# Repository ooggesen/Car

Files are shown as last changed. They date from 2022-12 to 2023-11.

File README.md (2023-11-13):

# Remote Car

This project contains the PCB, code and CAD files for a small remotely controlled car. It is based uppon an Arduino Micro.

The PCB files are generated with KiCAD and can be found in the folder Platine.

The code for running the car can be found in the folder Code/Car_Backend and the controller from which to access the car is stored in Car/Car_Frontend.

The folder Body contains stl files, from which the body of the car could be build

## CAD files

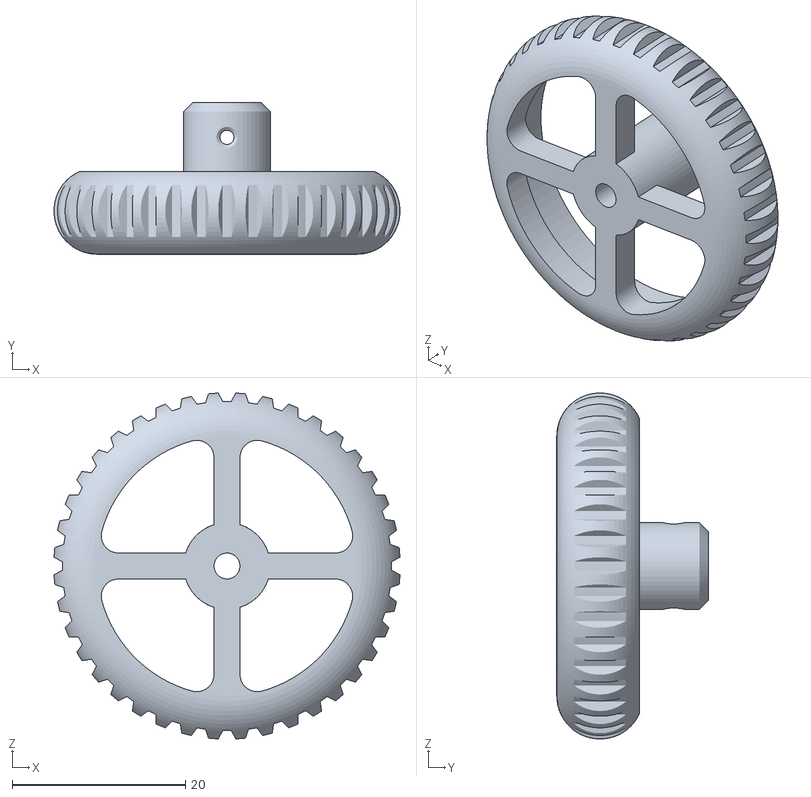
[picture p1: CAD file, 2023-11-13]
Body/Lenkrad v6.stl
39.9 x 17.5 x 39.9

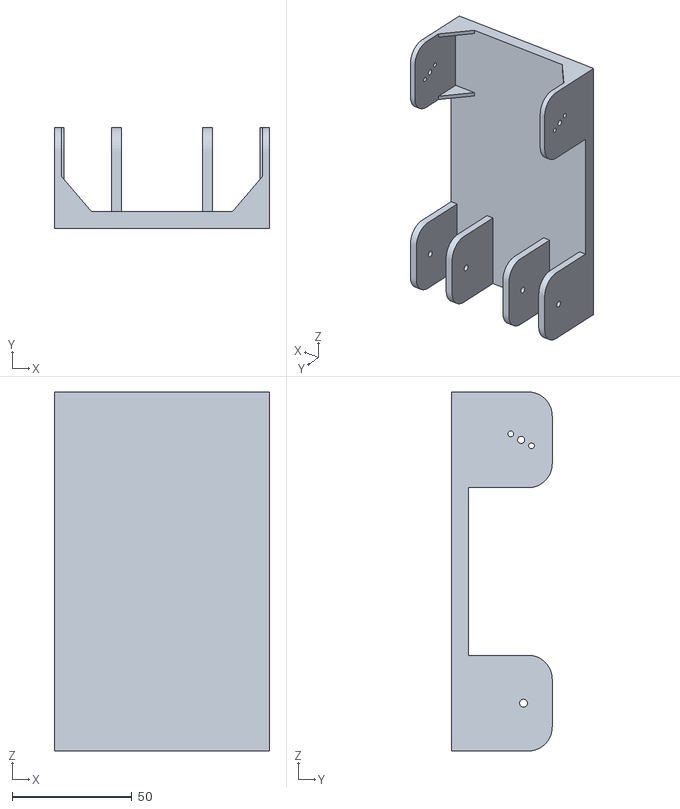
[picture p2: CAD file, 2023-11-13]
Body/Unterboden v4.stl
90.0 x 42.0 x 150.0

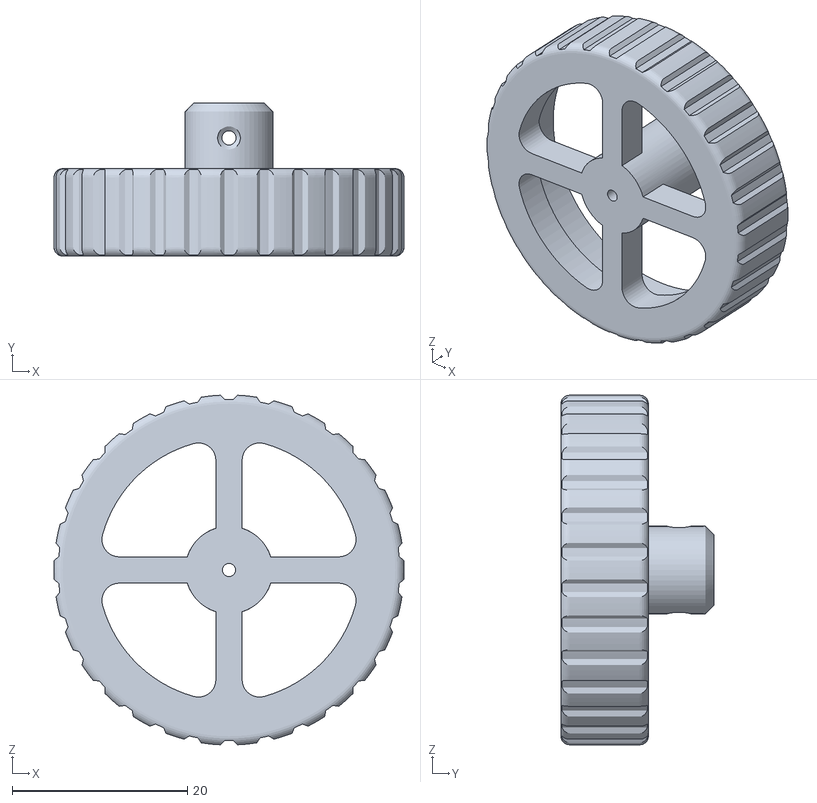
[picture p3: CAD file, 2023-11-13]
Body/Antriebsrad v4.stl
40.0 x 17.5 x 39.9

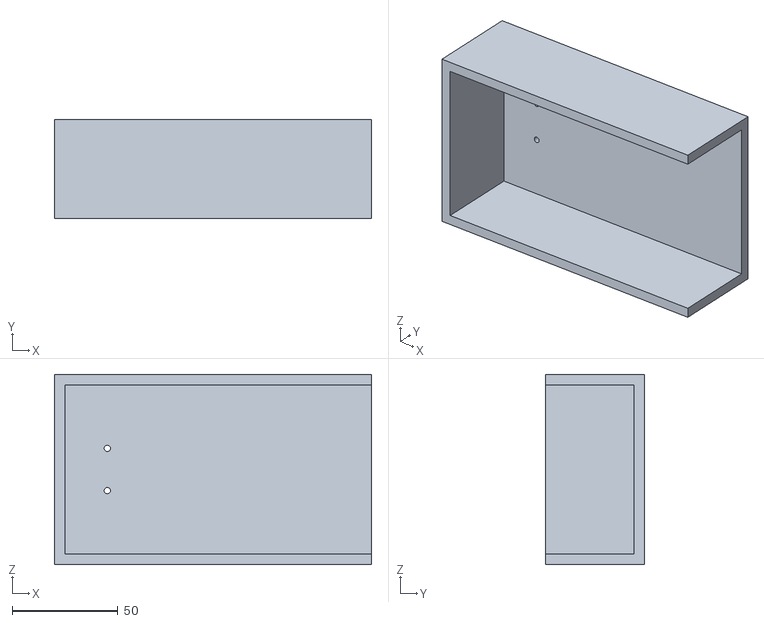
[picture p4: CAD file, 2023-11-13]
Body/Abdeckung.stl
150.0 x 47.0 x 90.0

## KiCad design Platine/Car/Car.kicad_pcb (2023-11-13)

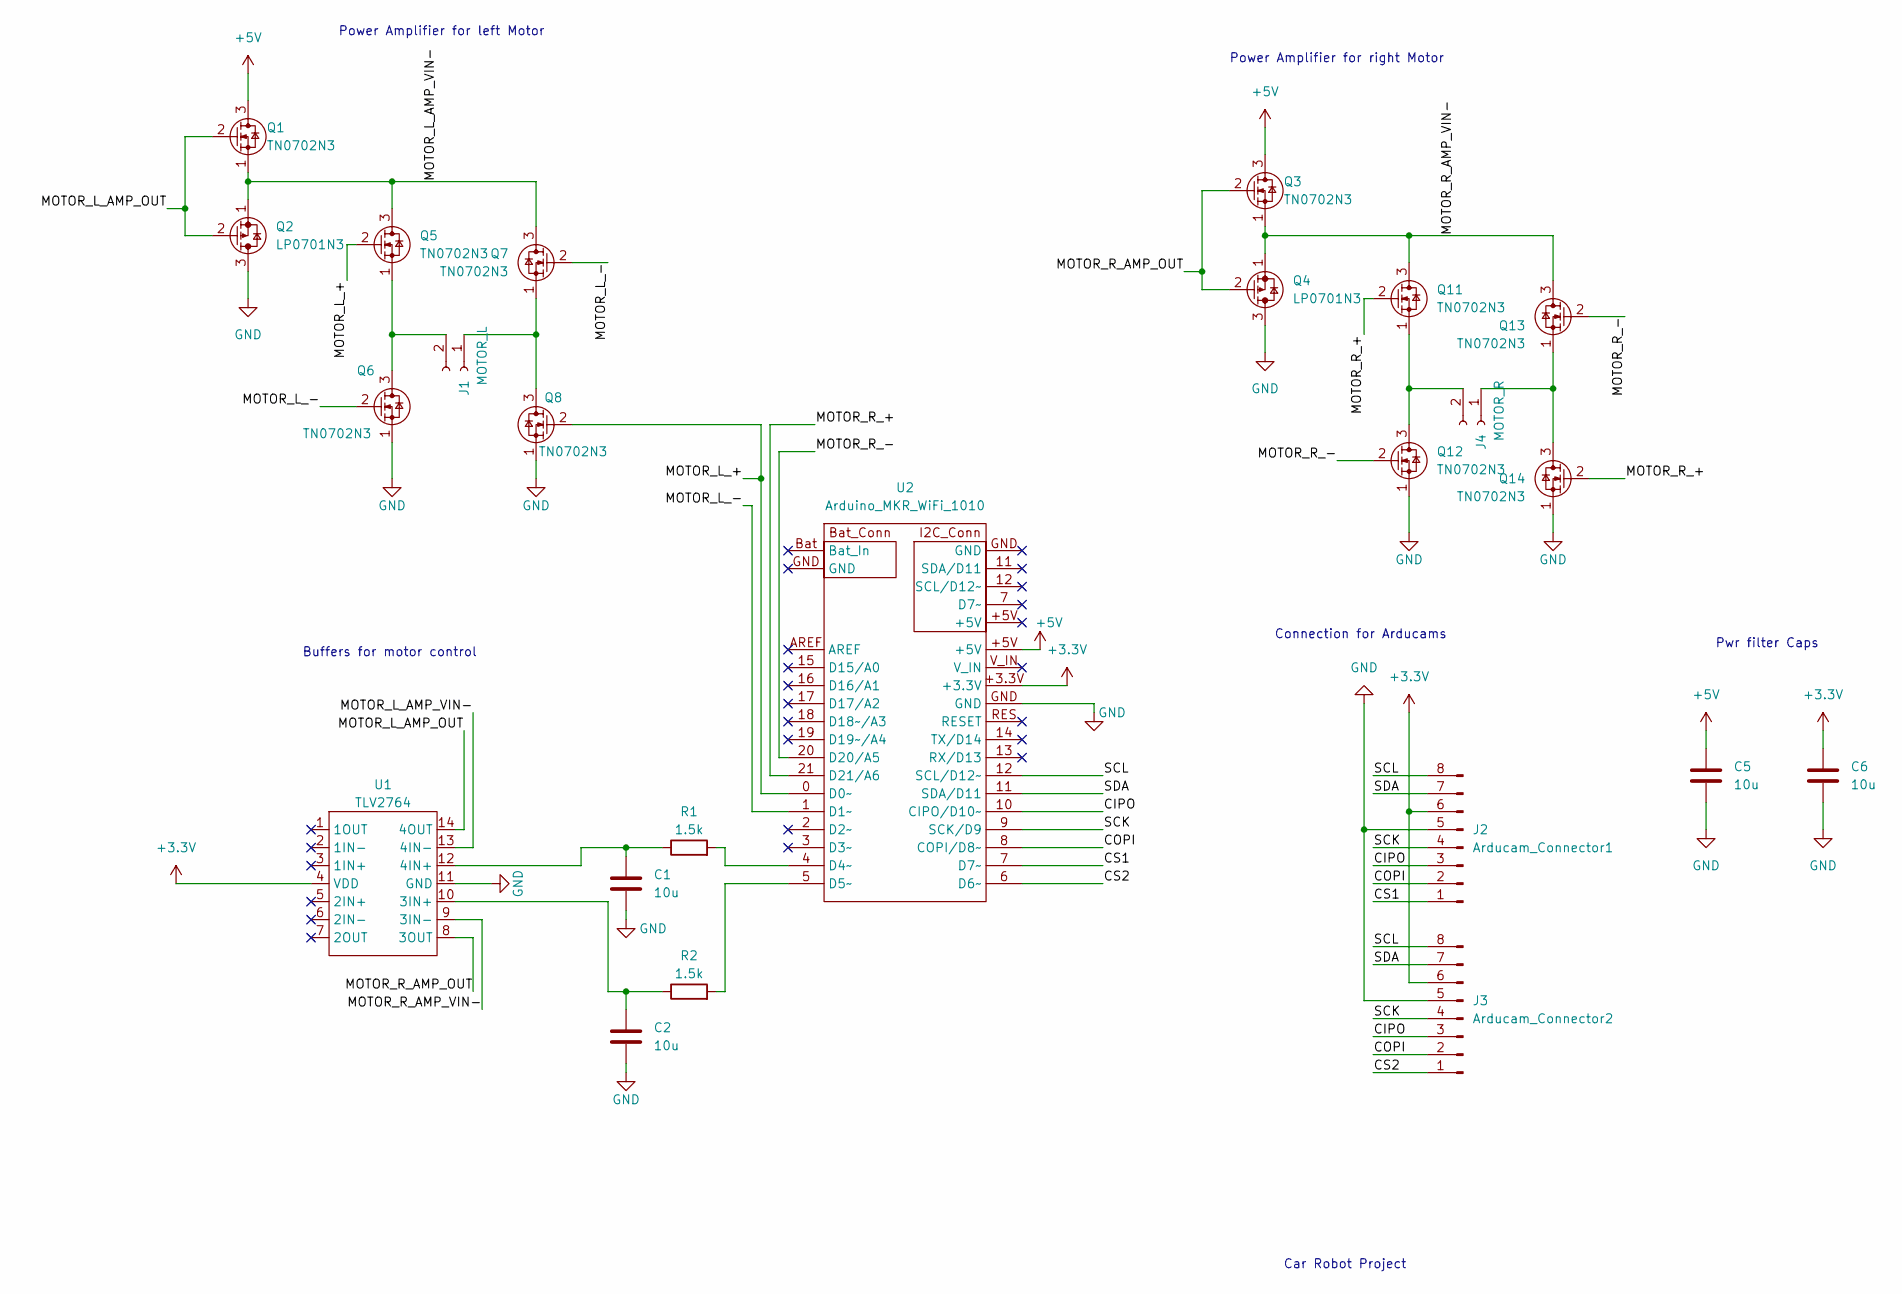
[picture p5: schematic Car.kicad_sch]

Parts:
C1, C2, C5, C6: 10u; CP_Radial_D5.0mm_P2.50mm
J1: MOTOR_L; PinHeader_1x02_P2.00mm_Vertical
J2: Arducam_Connector1; PinHeader_1x08_P2.54mm_Vertical
J3: Arducam_Connector2; PinHeader_1x08_P2.54mm_Vertical
J4: MOTOR_R; PinHeader_1x02_P2.00mm_Vertical
Q1, Q3, Q5, Q6, Q7, Q8, Q11, Q12, Q13, Q14: TN0702N3; TO-92L_Inline
Q2, Q4: LP0701N3; TO-92L_Inline
R1, R2: 1.5k; R_Axial_DIN0207_L6.3mm_D2.5mm_P10.16mm_Horizontal
U1: TLV2764; DIP-14_W7.62mm
U2: Arduino_MKR_WiFi_1010; Arduino_MKR_1010

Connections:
+3V3: C6.1, J2.6, J3.6, U1.4 (VDD), U2.+3.3V
+5V: C5.1, Q1.3, Q3.3, U2.+5V
/CIPO: J2.3, J3.3, U2.10 (CIPO/D10~)
/COPI: J2.2, J3.2, U2.8 (COPI/D8~)
/CS1: J2.1, U2.7 (D7~)
/CS2: J3.1, U2.6 (D6~)
/MOTOR_L_+: Q5.2, Q8.2, U2.0 (D0~)
/MOTOR_L_-: Q6.2, Q7.2, U2.1 (D1~)
/MOTOR_L_AMP_OUT: Q1.2, Q2.2, U1.14 (4OUT)
/MOTOR_L_AMP_VIN-: Q1.1, Q2.1, Q5.3, Q7.3, U1.13 (4IN-)
/MOTOR_R_+: Q11.2, Q14.2, U2.21 (D21/A6)
/MOTOR_R_-: Q12.2, Q13.2, U2.20 (D20/A5)
/MOTOR_R_AMP_OUT: Q3.2, Q4.2, U1.8 (3OUT)
/MOTOR_R_AMP_VIN-: Q3.1, Q4.1, Q11.3, Q13.3, U1.9 (3IN-)
/SCK: J2.4, J3.4, U2.9 (SCK/D9)
/SCL: J2.8, J3.8, U2.12 (SCL/D12~)
/SDA: J2.7, J3.7, U2.11 (SDA/D11)
GND: C1.2, C2.2, C5.2, C6.2, J2.5, J3.5, Q2.3, Q4.3, Q6.1, Q8.1, Q12.1, Q14.1, U1.11 (GND), U2.GND
unnamed: C1.1, R1.1, U1.12 (4IN+)
unnamed: C2.1, R2.1, U1.10 (3IN+)
unnamed: J1.1, Q7.1, Q8.3
unnamed: J1.2, Q5.1, Q6.3
unnamed: J4.1, Q13.1, Q14.3
unnamed: J4.2, Q11.1, Q12.3
unnamed: R1.2, U2.4 (D4~)
unnamed: R2.2, U2.5 (D5~)

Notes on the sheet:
Pwr filter Caps
Power Amplifier for right Motor
Buffers for motor control
Connection for Arducams
Car Robot Project
Power Amplifier for left Motor

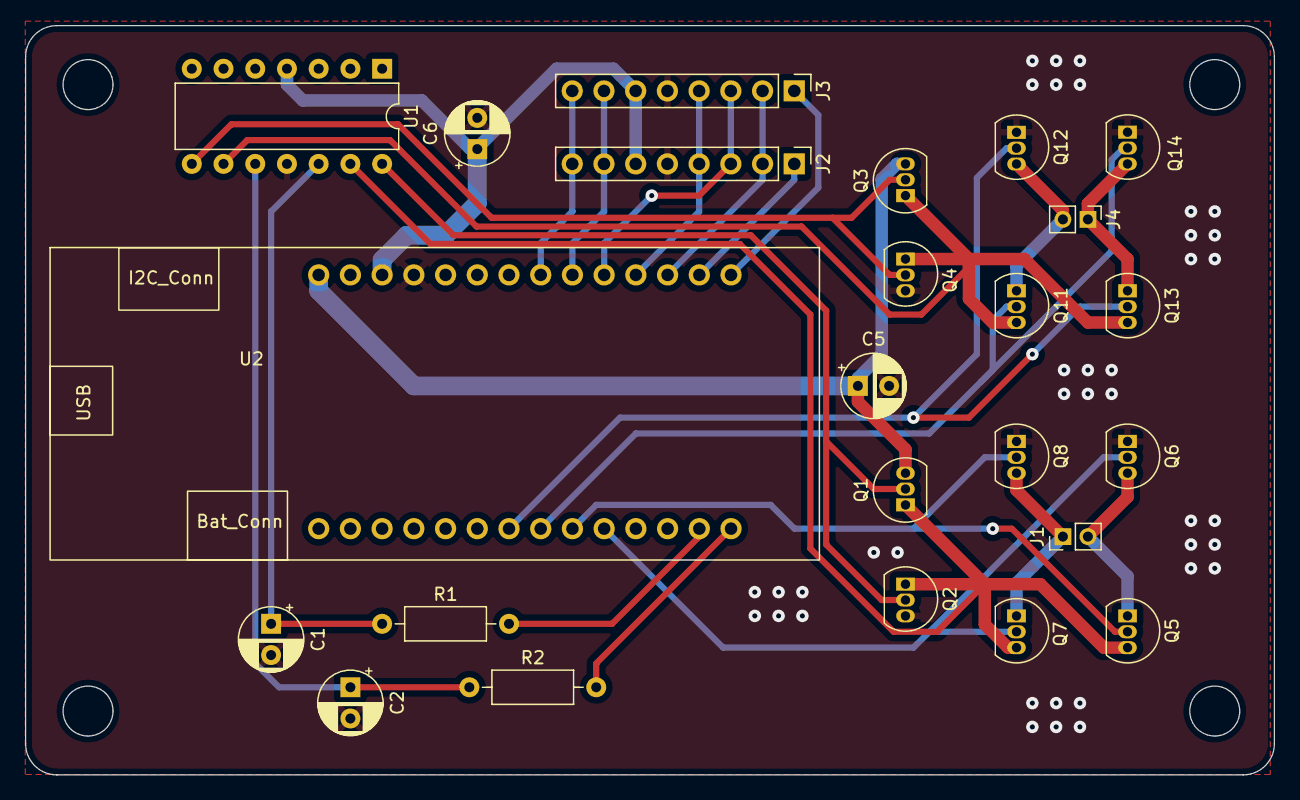
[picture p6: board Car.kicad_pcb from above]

Board: 2 copper layers, 100.0 x 60.0 mm, 24 parts (0 on the bottom side), 26 nets.

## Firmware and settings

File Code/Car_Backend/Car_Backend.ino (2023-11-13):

//#define WIFI_N_BT //Define if to use wifi instead of bluetooth, bluetooth not yet tested
#define DEBUG //define for debug feedback through Serial

#include "base.h"

void match_com(String in){
  if (in.indexOf("GET PHOTO_1") >= 0) {  
    println_debug("CMD: photo 1st camera!");
    cam_event = start_cap1;
  }else if (in.indexOf("GET PHOTO_2") >= 0 && two_cam) {
    println_debug("CMD: photo 2nd camera!");
    cam_event = start_cap2;
  }else if (in.indexOf("SET MOTOR_R") >= 0) {
    unsigned int index =  in.indexOf("SET MOTOR_R") + 12;
    int pwr = in.substring(index).toInt();
    set_motor(MOTOR_R, pwr);
    
    print_debug("CMD: r motor ");
    print_debug((String) pwr);
    print_debug(" \% power.\n");
  }else if (in.indexOf("SET MOTOR_L") >= 0) {
    unsigned int index =  in.indexOf("SET MOTOR_L") + 12;
    int pwr = in.substring(index).toInt();
    set_motor(MOTOR_L, pwr);
    
    print_debug("CMD: l motor ");
    print_debug((String) pwr);
    print_debug(" \% power.\n");
  }
}
//-----------------------------------setup-------------------------------------------------------------
void setup() {
  // put your setup code here, to run once:
  PT_INIT(&pt_send_photo);
  cam_state = idle;
  cam_event = def;
  
  init_motor();
  #ifdef DEBUG
    Serial.begin(9600);
    while(!Serial);
    Serial.println("\nStarting MKRWifi1010!");
  #endif

  #ifdef WIFI_N_BT
    PT_INIT(&pt_wifi_server);
    init_wifi();
  #else
    init_bluetooth();
  #endif
  
  init_arducam(&Cam1);
  
  if (two_cam){
    println_debug("Cam 2:");
    init_arducam(&Cam2);
  }
  println_debug("Setup done!\n");
  
  tests();
}

//-----------------------------------loop-------------------------------------------------------------

void loop() {
  #ifdef WIFI_N_BT
    PT_SCHEDULE(wifi_server_loop(&pt_wifi_server));
  #else
//    BLE.poll();
//    match_com((String)command.value());
    PT_SCHEDULE(bluetooth_receiver(&pt_bt_peripheral));
  #endif
  cam_fsm();
}

//------------------------------- debug stuff ----------------------------------
void tests(){
  println_debug("Starting tests!");
  //test_motor();
  test_arducam();
  #ifndef WIFI_N_BT
    test_bt();
  #endif
  println_debug("Test finished!\n");
}


void print_debug(String text){
  #ifdef DEBUG
    Serial.print(text);
    //Serial.flush();
  #endif
}

void println_debug(String text){
  #ifdef DEBUG
    Serial.println(text);
    //Serial.flush();
  #endif
}

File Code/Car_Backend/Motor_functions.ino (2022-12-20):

#include "my_motor.h"

void set_motor(char sel, int pwr_per){
  assert(pwr_per <= 100 && pwr_per >= -100);
  switch (sel){
    case MOTOR_L:
      update_motor(MOTOR_L_PLUS, MOTOR_L_MINUS, MOTOR_L_PIN, pwr_per);
      break;
    case MOTOR_R:
      update_motor(MOTOR_R_PLUS, MOTOR_R_MINUS, MOTOR_R_PIN, pwr_per);
      break;
  }
}

void init_motor(){
  pinMode(MOTOR_L_PIN, OUTPUT);
  pinMode(MOTOR_R_PIN, OUTPUT);
  pinMode(MOTOR_L_MINUS, OUTPUT);
  pinMode(MOTOR_L_PLUS, OUTPUT);
  pinMode(MOTOR_R_MINUS, OUTPUT);
  pinMode(MOTOR_R_PLUS, OUTPUT);

  analogWrite(MOTOR_L_PIN, 0);
  analogWrite(MOTOR_R_PIN, 0);

  digitalWrite(MOTOR_L_MINUS, HIGH);
  digitalWrite(MOTOR_L_PLUS, HIGH);

  digitalWrite(MOTOR_R_MINUS, HIGH);
  digitalWrite(MOTOR_R_PLUS, HIGH);
}

void test_motor(){
  {
    println_debug("Starting motor tests!");
  }
  for (int i = -100; i<=100; i+=10){
    print_debug("Setting pwr to: ");
    println_debug((String) i);  
    set_motor(MOTOR_L, i);
    delay(2000);
    //set_motor(MOTOR_R, i);
    //delay(2000);
  }
}

void update_motor(int motor_plus, int motor_minus, int motor_dir, int pwr_per){
  int pwm = 255 * abs(pwr_per)/100 * 3.55/5; //100 percent equals 3.55V -> max v out of opamp
  if (pwr_per == 0){
        analogWrite(motor_dir, 0);
        digitalWrite(motor_minus, HIGH);
        digitalWrite(motor_plus, HIGH);
      }else if (pwr_per < 0){
        digitalWrite(motor_plus, LOW);
        digitalWrite(motor_minus, HIGH);
        analogWrite(motor_dir, pwm);
      }else {
        digitalWrite(motor_minus, LOW);
        digitalWrite(motor_plus, HIGH);
        analogWrite(motor_dir, pwm);
  }
}

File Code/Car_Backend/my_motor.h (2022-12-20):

#ifndef MY_MOTOR.H
#define MY_MOTOR.H

#include <assert.h>

#define MOTOR_L 1
#define MOTOR_R 2
#define MOTOR_L_PIN 4
#define MOTOR_R_PIN 5
#define MOTOR_L_PLUS 0
#define MOTOR_L_MINUS 1
#define MOTOR_R_PLUS 21
#define MOTOR_R_MINUS 20

void set_motor(char sel, int pwr_per);
void init_motor();
void test_motor();
void update_motor(int motor_plus, int motor_minus, int motor_dir, int pwr_per); 
void init_buff();

#endif //MY_MOTOR.H

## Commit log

2022-08-31 Initial commit. Software running motors and wifi connection testet. Hardware support for motors tested.
    [Car.kicad_pcb, Car.kicad_sch, Simulation.kicad_sch]
2022-10-17 Car software tested for motor control and camera capture. Success
2022-10-28 Sending and receiving of photo tested. With addtional conditions in Server backend, which check the beginning and ending of a jpeg frame.
2022-10-29 Changed reception of messages to bytesarray, with recognition of the end of the jpg frame. All image qualities work now.
2022-12-20 Refactoring the backend code
    [Car.kicad_sch, Simulation.kicad_sch]
2023-03-18 First verion on pcb tested and functional.
    [Abdeckung.stl, Antriebsrad v4.stl, Car.kicad_pcb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]
